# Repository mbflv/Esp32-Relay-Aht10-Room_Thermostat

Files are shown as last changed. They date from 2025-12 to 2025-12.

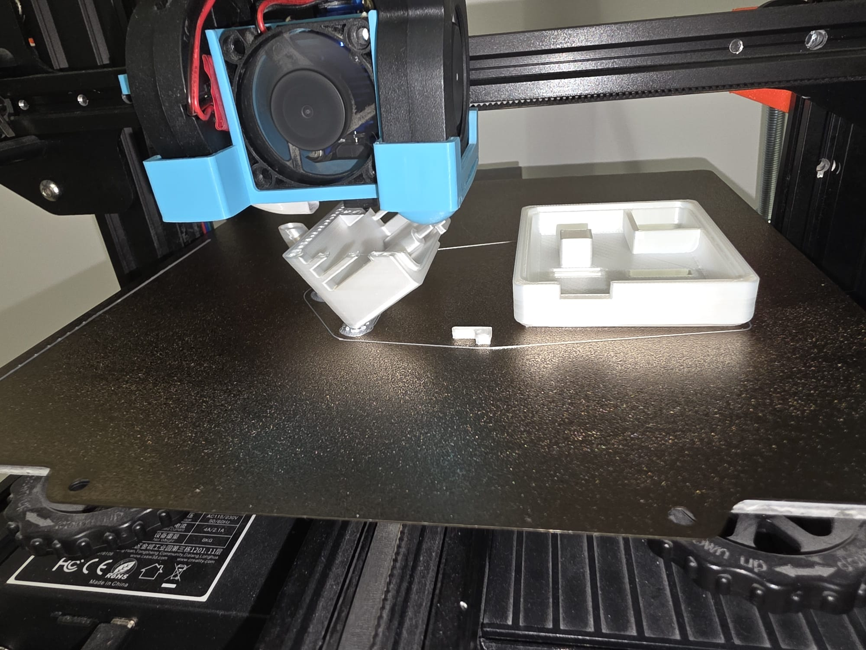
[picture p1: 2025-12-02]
Pictures/printing.png

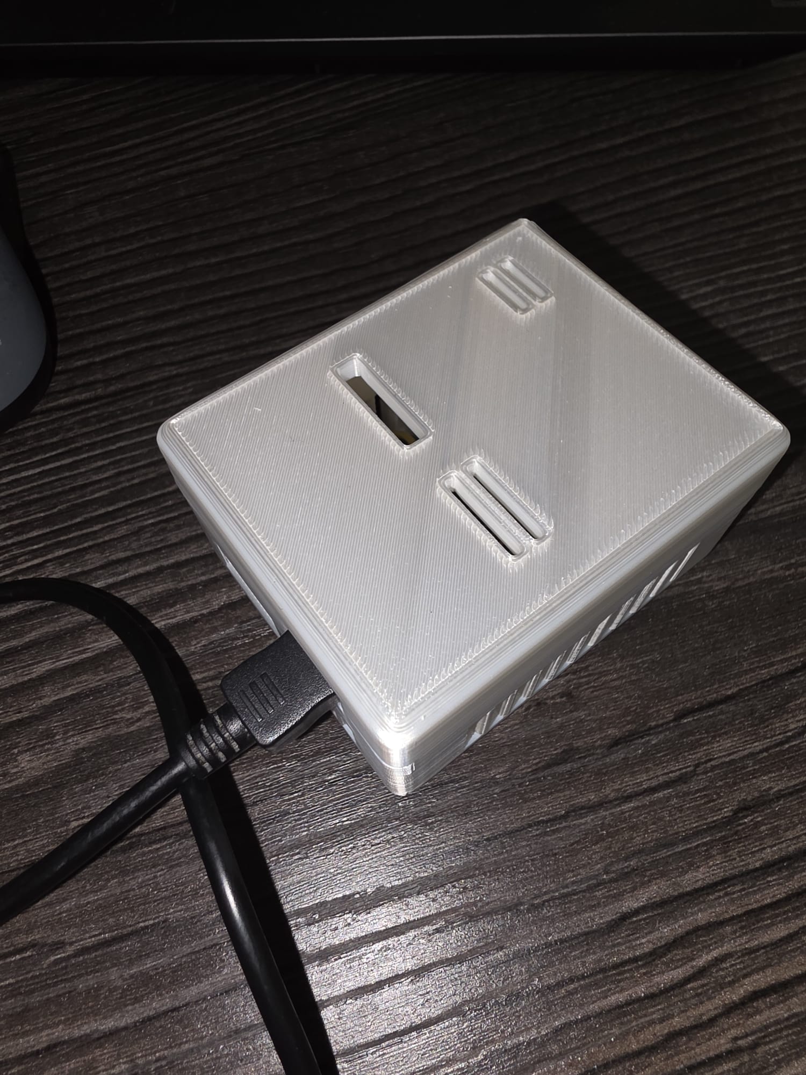
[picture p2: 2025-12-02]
Pictures/aht10_1.jpeg

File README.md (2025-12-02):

#Esp32-Relay-Aht10-Room_Thermostat

#
This is a room thermostat from at least 2 esp32 pcb.Big advantage of this system is that it use wifi local connection and AP to setup it using WEB UI.
It have many options to calibrate temperature and humidity, set up four schedule program and a graph history.
Another advantage of it is that it can support maximum 8 sensor from local Wifi.In Web UI you'll find that option to add/remove a new sensor and the check box that can make which sensor can be the main sensor who will be in control of the relay.
Esp32+relay is the brain of this configuration,it listening on port 80.you cand open a port from your rooter and acces if from outside of your house.
The big thing: NO need screw, or iron soldering, you will need only a few drops of superglue.It is not necessary to unsolder the pins from PCBs.You will can use them for the future projects.
Poll interval sensor is 60 seconds, it is permanent parameter.
Debounce is 60 seconds by default, and it can be modify.
You can install a button to factory reset using Pin 5, or you can find Factory reset button on web UI.
Another thing is about you can set offset to make correction directly on esp32+aht1 sensor UI or on relay board UI via wifi.

#
1st: esp32+relay which command your heater
  Pin connection from relay to esp board :
 IN -> pin 25
 GND -> GND
 VCC -> VN +5V

2nr esp32 + aht10 temp/hum sensor
  Pin connection from aht10 to esp board :
VIN ->3V3 +3V
GND -> GND
SCL -> G22
SDA -> G21

#
Easy method to flash esp32(Flash download Tool):
load xxxx.bootloader.bin Address: 0x1000
load xxxx.partition.bin  Address: 0x8000
load xxxx.ino.bin        Address: 0x10000
#
After flashing need to reset the board!!! after that AP will appear and you can change connection to your local wifi network!

Or you can use other IDE (Arduino IDE, etc..) and use the code to upload it.
It is nice because all code is formed in one file, and it is easy for everyone to flash it.

#
You can find in this place the *.3mf project for the case to print it for both: pcb+relay & pcb+aht10 sensor.

Material:Pla
Can be print with infill 20%
any printer any speed
recomanded bottom part to be inclined at 60degrees using manual supports and activate autobrim!

TO DO:
manual increase/decrease sensor polling time;
OTA firmare update.

I do not take responsibility for any malfunction, you do it on your own. Pay attention to the process of connecting to your heater because this relay only has an ON/OFF function. Do not connect voltage to the relay.

Goodluck!

If this project is usefull, i'd like to drink a coffe together: ( paypal: flav.op.nick@gmail.com )

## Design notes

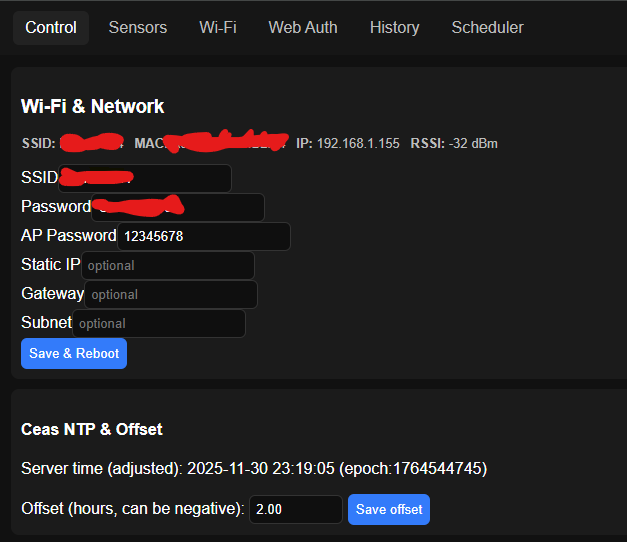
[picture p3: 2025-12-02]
Pictures/wifi.png

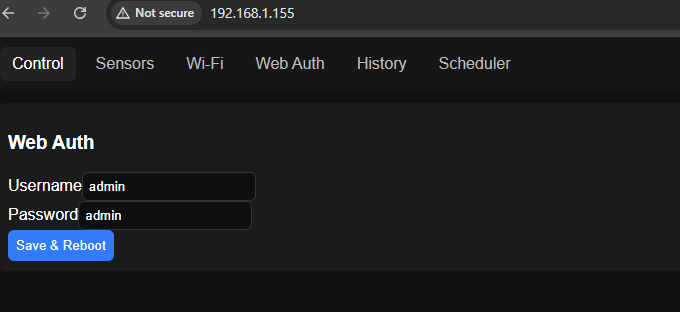
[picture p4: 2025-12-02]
Pictures/webauth.png

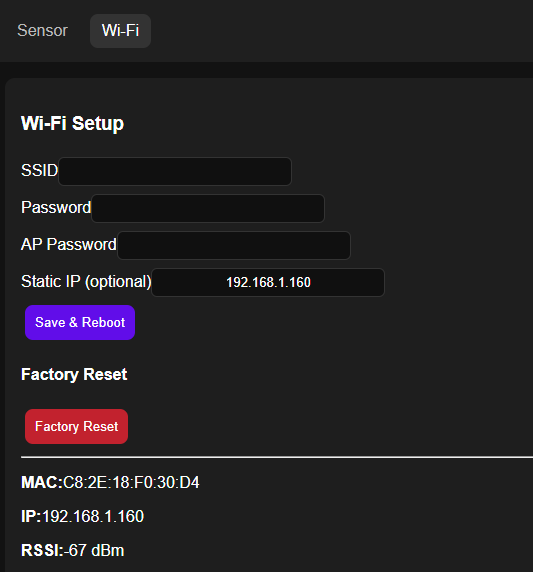
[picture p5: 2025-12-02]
Pictures/sensor-wifi.png

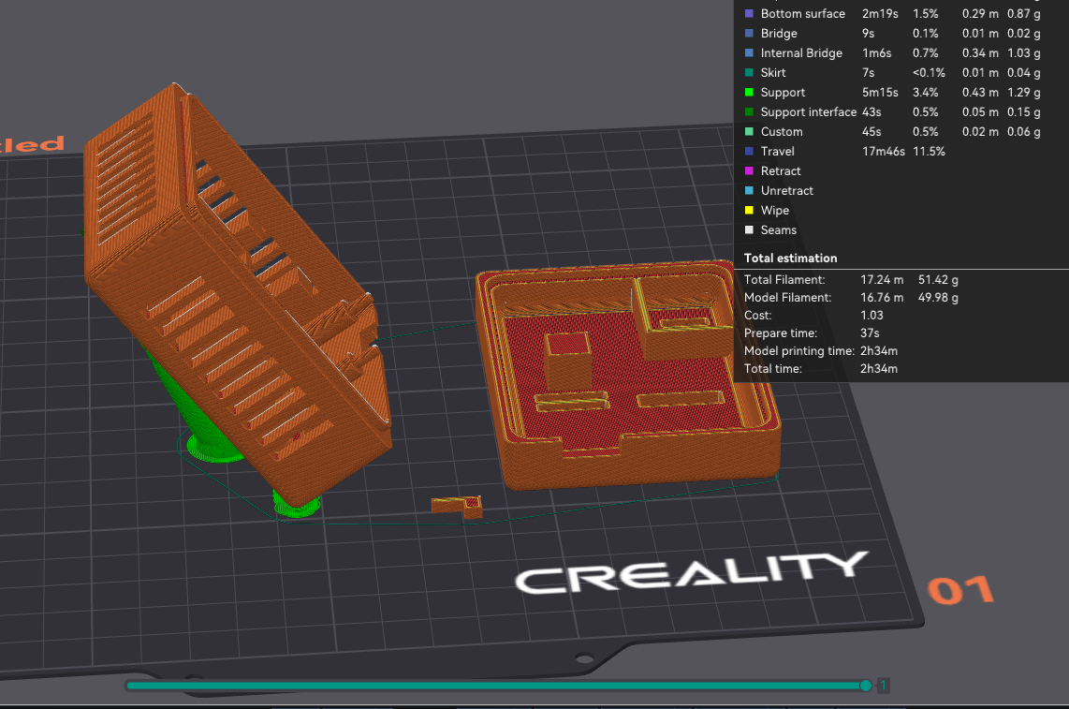
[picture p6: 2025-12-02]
Pictures/plate arrangement.png

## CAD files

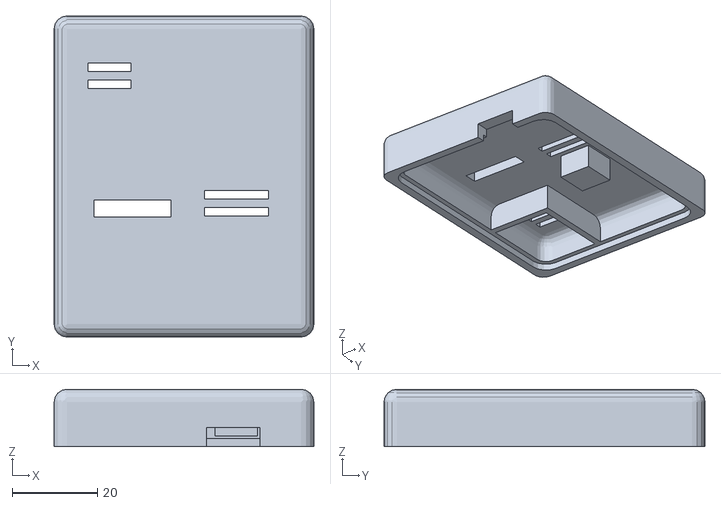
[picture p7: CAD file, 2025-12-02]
Printable Case/top.stl
61.0 x 75.4 x 13.5

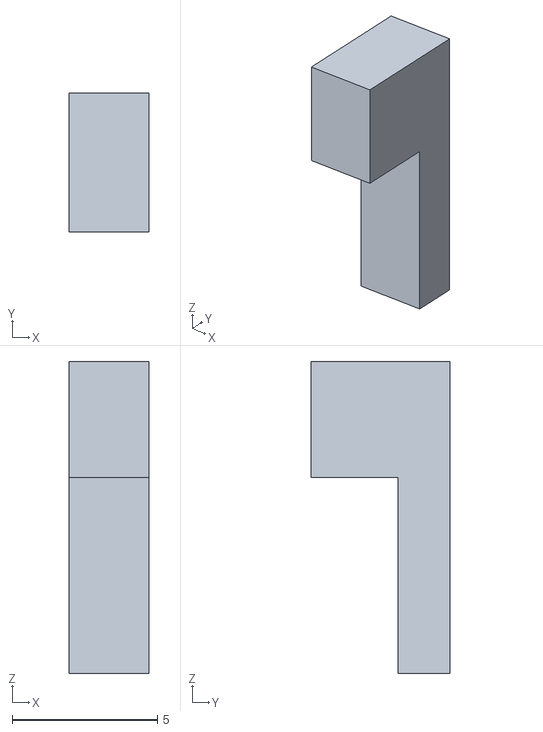
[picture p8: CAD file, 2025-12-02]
Printable Case/pin.stl
2.75 x 4.80 x 10.7

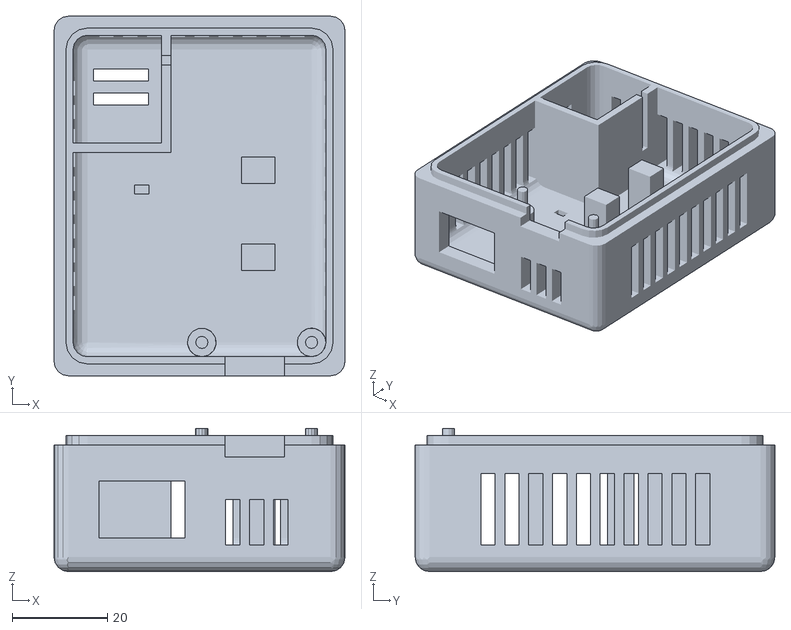
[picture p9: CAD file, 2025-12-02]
Printable Case/bot.stl
61.0 x 75.4 x 30.0

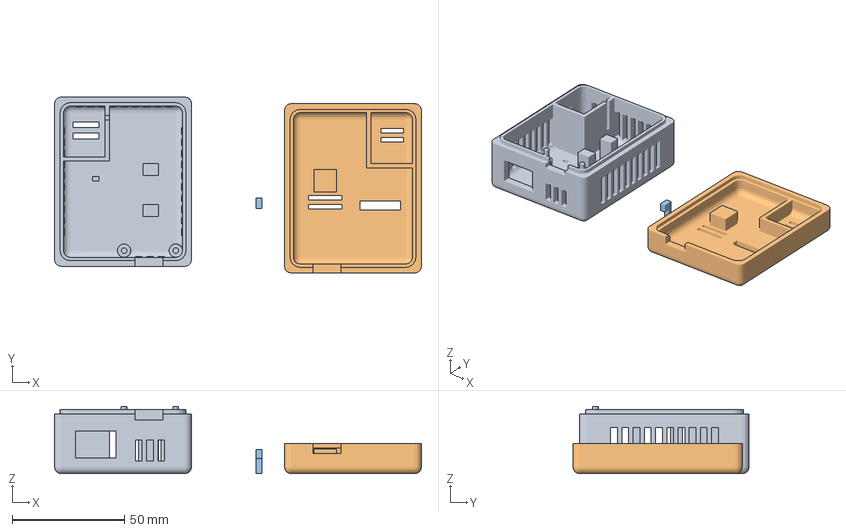
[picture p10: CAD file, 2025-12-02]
Printable Case/esp32_case_relay_aht10.3mf
163.4 x 78.3 x 30.0 mm
bot.stl
top.stl
pin.stl

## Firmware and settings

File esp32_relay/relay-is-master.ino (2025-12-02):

/* relay-with-sensors-variantA_ram_ntp_tooltip_final.ino
   For: ESP32 Dev Module
   - RAM history only
   - NTP clock with manual timezone offset (saved in Preferences)
   - History chart with hover tooltip (date/time, set.temp and temp)
   - Relay status shown on Sensors page
   - WiFi (AP + optional STA), Preferences for settings
   - Sensors polled via HTTP /json (temp/hum)
   - Scheduler + debounce + hysteresis
   - All settings persisted in Preferences
*/

#include <WiFi.h>
#include <WebServer.h>
#include <Preferences.h>
#include <HTTPClient.h>
#include <ArduinoJson.h>
#include <time.h>

#define RELAY_PIN 25
#define BUTTON_PIN 5
#define MAX_SENSORS 8
#define HISTORY_SLOTS 96            // number of samples per sensor in RAM
#define HISTORY_INTERVAL_MIN 30      // minutes between stored history samples (1 = every minute)
#define POLL_INTERVAL_MS 60000UL
#define DEFAULT_DEBOUNCE_SECS 1

WebServer server(80);
Preferences prefs;

// Auth default
String AUTH_USER = "admin";
String AUTH_PASS = "admin";

// WiFi defaults
String defaultAPPass = "12345678";
String apPass;
String savedSSID = "";
String savedPASS = "";
String staticIP = "";
String gatewayIP = "";
String subnetMask = "";

// Timezone offset in minutes (can be negative). Saved in prefs key "tz_min"
long tzOffsetMinutes = 0;

// Relay and button
bool relayState = false;
unsigned long pressStartTime = 0;
bool buttonPressed = false;

// Debounce
unsigned long lastDesiredRelayChange = 0;
unsigned long debounceSeconds = DEFAULT_DEBOUNCE_SECS * 1000UL;
bool desiredRelayState = false;

// Scheduler: 4 programs
struct Program {
  int startHour;
  int stopHour;
  float setTemp;
  bool enabled;
};
Program programs[4];

// Sensor struct
struct Sensor {
  String name;
  String ip;
  float tempOffset;
  float humOffset;
  float setTemp;
  float hysteresis;
  float lastTemp;
  float lastHum;
  bool isMain;
  bool enabled;
};
Sensor sensors[MAX_SENSORS];

// History entry (RAM)
struct HistEntry {
  uint32_t ts;
  float temp;
  float hum;
  float setTemp;
};
// In-RAM circular buffers
HistEntry histBuf[MAX_SENSORS][HISTORY_SLOTS];
uint16_t histIdx[MAX_SENSORS]; // next write position (0..HISTORY_SLOTS-1)

// Helpers
String f1(float v){ return String(v,1); }
void relayOn(){ pinMode(RELAY_PIN, OUTPUT); digitalWrite(RELAY_PIN, LOW); relayState=true; }
void relayOff(){ pinMode(RELAY_PIN, INPUT); digitalWrite(RELAY_PIN, LOW); relayState=false; } // open-drain style

// Preferences key helpers
String prefKeySensor(int idx, const char* k){
  char buf[32]; snprintf(buf, sizeof(buf), "s%d_%s", idx, k); return String(buf);
}
String prefKeyProg(int p, const char* k){ char buf[32]; snprintf(buf,sizeof(buf),"prog%d_%s",p,k); return String(buf); }

// Factory reset
void factoryReset(){
  prefs.begin("wifi", false); prefs.clear(); prefs.end();
  prefs.begin("sensors", false); prefs.clear(); prefs.end();
  prefs.begin("prog", false); prefs.clear(); prefs.end();
  delay(500);
  ESP.restart();
}

// Load / Save sensors & programs & prefs
void loadSensors(){
  prefs.begin("sensors", true);
  for(int i=0;i<MAX_SENSORS;i++){
    sensors[i].ip = prefs.getString(prefKeySensor(i,"ip").c_str(), "");
    sensors[i].name = prefs.getString(prefKeySensor(i,"name").c_str(), String("Sensor " + String(i+1)));
    sensors[i].tempOffset = prefs.getFloat(prefKeySensor(i,"toff").c_str(), 0.0f);
    sensors[i].humOffset = prefs.getFloat(prefKeySensor(i,"hoff").c_str(), 0.0f);
    sensors[i].setTemp = prefs.getFloat(prefKeySensor(i,"set").c_str(), 25.0f);
    sensors[i].hysteresis = prefs.getFloat(prefKeySensor(i,"hys").c_str(), 1.0f);
    sensors[i].isMain = prefs.getBool(prefKeySensor(i,"main").c_str(), false);
    sensors[i].lastTemp = NAN;
    sensors[i].lastHum = NAN;
    sensors[i].enabled = (sensors[i].ip.length() > 0);
  }
  prefs.end();
}

void saveSensors(){
  prefs.begin("sensors", false);
  for(int i=0;i<MAX_SENSORS;i++){
    prefs.putString(prefKeySensor(i,"ip").c_str(), sensors[i].ip);
    prefs.putString(prefKeySensor(i,"name").c_str(), sensors[i].name);
    prefs.putFloat(prefKeySensor(i,"toff").c_str(), sensors[i].tempOffset);
    prefs.putFloat(prefKeySensor(i,"hoff").c_str(), sensors[i].humOffset);
    prefs.putFloat(prefKeySensor(i,"set").c_str(), sensors[i].setTemp);
    prefs.putFloat(prefKeySensor(i,"hys").c_str(), sensors[i].hysteresis);
    prefs.putBool(prefKeySensor(i,"main").c_str(), sensors[i].isMain);
  }
  prefs.end();
}

void loadPrograms(){
  prefs.begin("prog", true);
  for(int p=0;p<4;p++){
    programs[p].startHour = prefs.getInt(prefKeyProg(p,"start").c_str(), 0);
    programs[p].stopHour  = prefs.getInt(prefKeyProg(p,"stop").c_str(), 0);
    programs[p].setTemp   = prefs.getFloat(prefKeyProg(p,"temp").c_str(), 20.0);
    programs[p].enabled   = prefs.getBool(prefKeyProg(p,"en").c_str(), false);
  }
  prefs.end();
}

void savePrograms(){
  prefs.begin("prog", false);
  for(int p=0;p<4;p++){
    prefs.putInt(prefKeyProg(p,"start").c_str(), programs[p].startHour);
    prefs.putInt(prefKeyProg(p,"stop").c_str(), programs[p].stopHour);
    prefs.putFloat(prefKeyProg(p,"temp").c_str(), programs[p].setTemp);
    prefs.putBool(prefKeyProg(p,"en").c_str(), programs[p].enabled);
  }
  prefs.end();
}

void loadWifiAuth(){
  prefs.begin("wifi", true);
  savedSSID = prefs.getString("ssid", "");
  savedPASS = prefs.getString("pass", "");
  apPass = prefs.getString("appass", defaultAPPass);
  staticIP = prefs.getString("ip", "");
  gatewayIP = prefs.getString("gw", "");
  subnetMask = prefs.getString("subnet", "");
  AUTH_USER = prefs.getString("auth_user", "admin");
  AUTH_PASS = prefs.getString("auth_pass", "admin");
  uint32_t db = prefs.getUInt("deb_ms", DEFAULT_DEBOUNCE_SECS * 1000UL);
  debounceSeconds = db;
  tzOffsetMinutes = prefs.getLong("tz_min", 0); // load timezone offset minutes
  prefs.end();
}
void saveWifiAuth(){
  prefs.begin("wifi", false);
  prefs.putString("ssid", savedSSID);
  prefs.putString("pass", savedPASS);
  prefs.putString("appass", apPass);
  prefs.putString("ip", staticIP);
  prefs.putString("gw", gatewayIP);
  prefs.putString("subnet", subnetMask);
  prefs.putString("auth_user", AUTH_USER);
  prefs.putString("auth_pass", AUTH_PASS);
  prefs.putUInt("deb_ms", (uint32_t)debounceSeconds);
  prefs.putLong("tz_min", tzOffsetMinutes);
  prefs.end();
}

// ===== In-RAM history helpers =====
void initHistoryRam(){
  for(int i=0;i<MAX_SENSORS;i++){
    histIdx[i] = 0;
    for(int s=0;s<HISTORY_SLOTS;s++){
      histBuf[i][s].ts = 0;
      histBuf[i][s].temp = NAN;
      histBuf[i][s].hum = NAN;
      histBuf[i][s].setTemp = 0;
    }
  }
}

void appendHistoryRam(int si, uint32_t ts, float temp, float hum, float setT){
  if(si<0 || si>=MAX_SENSORS) return;
  uint16_t idx = histIdx[si] % HISTORY_SLOTS;
  histBuf[si][idx].ts = ts;
  histBuf[si][idx].temp = temp;
  histBuf[si][idx].hum = hum;
  histBuf[si][idx].setTemp = setT;
  histIdx[si] = (idx + 1) % HISTORY_SLOTS;
}

// Build JSON history oldest->newest into provided JsonArray
void jsonHistoryForSensor(int si, JsonArray &arr){
  if(si<0 || si>=MAX_SENSORS) return;
  uint16_t w = histIdx[si] % HISTORY_SLOTS; // next write pos; oldest at w
  for(int i=0;i<HISTORY_SLOTS;i++){
    int pos = (w + i) % HISTORY_SLOTS;
    if(histBuf[si][pos].ts == 0) continue;
    JsonObject o = arr.createNestedObject();
    o["ts"] = histBuf[si][pos].ts - tzOffsetMinutes*60;

    //o["ts"] = histBuf[si][pos].ts;
    if(isnan(histBuf[si][pos].temp)) o["temp"] = nullptr; else o["temp"] = histBuf[si][pos].temp;
    if(isnan(histBuf[si][pos].hum))  o["hum"]  = nullptr; else o["hum"]  = histBuf[si][pos].hum;
    o["set"] = histBuf[si][pos].setTemp;
  }
}

// ===== Poll single sensor by IP (expects JSON with fields "temp" and "hum") =====
bool pollSensor(int idx){
  if(idx<0 || idx>=MAX_SENSORS) return false;
  if(!sensors[idx].enabled || sensors[idx].ip.length()==0) return false;

  HTTPClient http;
  String url = "http://" + sensors[idx].ip + "/json";
  http.setTimeout(3000);
  if(!http.begin(url)) {
    http.end();
    return false;
  }
  int code = http.GET();
  if(code==200){
    String payload = http.getString();
    http.end();
    StaticJsonDocument<256> doc;
    DeserializationError err = deserializeJson(doc, payload);
    if(!err){
      float t = NAN, h = NAN;
      if(doc.containsKey("temp")) t = doc["temp"].as<float>();
      else if(doc.containsKey("temperature")) t = doc["temperature"].as<float>();
      if(doc.containsKey("hum")) h = doc["hum"].as<float>();
      else if(doc.containsKey("humidity")) h = doc["humidity"].as<float>();
      if(!isnan(t)) sensors[idx].lastTemp = t + sensors[idx].tempOffset;
      if(!isnan(h)) sensors[idx].lastHum = h + sensors[idx].humOffset;
      return true;
    }
  } else {
    http.end();
  }
  return false;
}

// ===== JSON endpoints =====
void handleSensorsJson(){
  DynamicJsonDocument doc(2048);
  doc["relay"] = relayState ? "ON" : "OFF";
  JsonArray arr = doc.createNestedArray("sensors");
  for(int i=0;i<MAX_SENSORS;i++){
    if(!sensors[i].enabled) continue;
    JsonObject s = arr.createNestedObject();
    s["index"] = i;
    s["name"] = sensors[i].name;
    s["ip"] = sensors[i].ip;
    if(isnan(sensors[i].lastTemp)) s["temp"] = nullptr; else s["temp"] = sensors[i].lastTemp;
    if(isnan(sensors[i].lastHum))  s["hum"] = nullptr;  else s["hum"] = sensors[i].lastHum;
    s["toff"] = sensors[i].tempOffset;
    s["hoff"] = sensors[i].humOffset;
    s["set"]  = sensors[i].setTemp;
    s["hys"]  = sensors[i].hysteresis;
    s["main"] = sensors[i].isMain;
  }
  String out; serializeJson(doc, out);
  server.send(200, "application/json", out);
}

// History JSON
void handleHistoryJson(){
  if(!server.authenticate(AUTH_USER.c_str(), AUTH_PASS.c_str())) return server.requestAuthentication();
  int si = server.arg("i").toInt();
  if(si<0 || si>=MAX_SENSORS){ server.send(400,"text/plain","Bad index"); return; }
  DynamicJsonDocument doc(4096 + HISTORY_SLOTS*48);
  doc["sensor"] = sensors[si].name;
  doc["index"] = si;
  JsonArray arr = doc.createNestedArray("history");
  jsonHistoryForSensor(si, arr);
  String out; serializeJson(doc, out);
  server.send(200,"application/json", out);
}

// Time endpoint (returns adjusted epoch and ISO string)
String isoFromEpoch(time_t t){
  struct tm tmnow;
  gmtime_r(&t, &tmnow);
  char buf[32];
  snprintf(buf, sizeof(buf), "%04d-%02d-%02d %02d:%02d:%02d",
           tmnow.tm_year+1900, tmnow.tm_mon+1, tmnow.tm_mday,
           tmnow.tm_hour, tmnow.tm_min, tmnow.tm_sec);
  return String(buf);
}
void handleTimeJson(){
  time_t nowt = time(NULL);
  if(nowt <= 0) {
    server.send(200,"application/json","{\"epoch\":0,\"iso\":\"N/A\"}");
    return;
  }
  long adj = nowt + tzOffsetMinutes * 60;
  String out = "{\"epoch\":" + String((uint32_t)adj) + ",\"iso\":\"" + isoFromEpoch((time_t)adj) + "\"}";
  server.send(200,"application/json", out);
}

// ===== Web UI root (inline HTML + JS) =====
void handleRoot(){
  if(!server.authenticate(AUTH_USER.c_str(), AUTH_PASS.c_str())) return server.requestAuthentication();

  String macStr = WiFi.macAddress();
  String ipStr = (WiFi.status()==WL_CONNECTED) ? WiFi.localIP().toString() : "N/A";
  long rssi = WiFi.RSSI();
  String rssiStr = (WiFi.status()==WL_CONNECTED) ? String(rssi)+" dBm" : "N/A";

  // Build sensors HTML cards, include relay status at top
  String sensorsHtml = "";
  sensorsHtml += "<div class='card'><h3>Relay status</h3><p id='relayStateMain'>--</p></div>";
  for(int i=0;i<MAX_SENSORS;i++){
    if(!sensors[i].enabled) continue;
    sensorsHtml += "<div class='card' id='sensorCard"+String(i)+"'>";
    sensorsHtml += "<h4><input class='sname' id='name"+String(i)+"' value='"+sensors[i].name+"' onblur='saveName("+String(i)+")'></h4>";
    sensorsHtml += "<p><b>IP:</b> "+sensors[i].ip+"</p>";
    sensorsHtml += "<p>Temp: <span id='temp"+String(i)+"'>"+ (isnan(sensors[i].lastTemp)?"--":f1(sensors[i].lastTemp)) +"</span>&deg;C  Hum: <span id='hum"+String(i)+"'>"+ (isnan(sensors[i].lastHum)?"--":f1(sensors[i].lastHum)) +"</span>%</p>";
    sensorsHtml += "<p>Set: <button class='small' onclick='adjSet("+String(i)+",-0.1)'>-</button> <span id='set"+String(i)+"'>"+f1(sensors[i].setTemp)+"</span> <button class='small' onclick='adjSet("+String(i)+",0.1)'>+</button></p>";
    sensorsHtml += "<p>Hyst: <button class='small' onclick='adjHys("+String(i)+",-0.1)'>-</button> <span id='hys"+String(i)+"'>"+f1(sensors[i].hysteresis)+"</span> <button class='small' onclick='adjHys("+String(i)+",0.1)'>+</button></p>";
    sensorsHtml += "<p>Offset T: <button class='small' onclick='adjOff("+String(i)+",-0.1)'>-</button> <span id='offt"+String(i)+"'>"+f1(sensors[i].tempOffset)+"</span> <button class='small' onclick='adjOff("+String(i)+",0.1)'>+</button></p>";
    sensorsHtml += "<p>Offset H: <button class='small' onclick='adjOffH("+String(i)+",-0.1)'>-</button> <span id='offh"+String(i)+"'>"+f1(sensors[i].humOffset)+"</span> <button class='small' onclick='adjOffH("+String(i)+",0.1)'>+</button></p>";
    sensorsHtml += "<p><label><input type='radio' name='mainSensor' onchange='setMain("+String(i)+")' "+(sensors[i].isMain?"checked":"")+"> Main sensor</label></p>";
    sensorsHtml += "<p><button class='del' onclick='removeSensor("+String(i)+")'>Remove</button> <button class='btn' onclick='viewHistory("+String(i)+")'>History</button></p>";
    sensorsHtml += "</div>";
  }

  // Add-sensor UI
  bool canAdd = false;
  for(int i=0;i<MAX_SENSORS;i++){ if(!sensors[i].enabled){ canAdd=true; break; } }
  String addHtml = "";
  if(canAdd){
    addHtml += "<div class='card'><h4>Add Sensor</h4>";
    addHtml += "<label>IP</label><input id='add_ip' class='tiny' placeholder='192.168.1.50'><br>";
    addHtml += "<label>Name</label><input id='add_name' class='tiny' placeholder='Livingroom'><br>";
    addHtml += "<button class='btn' onclick='addSensor()'>Add sensor</button></div>";
  } else {
    addHtml += "<div class='card'><p>Max sensors reached ("+String(MAX_SENSORS)+")</p></div>";
  }

  // Programs UI
  String progHtml = "<div class='card'><h4>Scheduler (4 programs)</h4>";
  for(int p=0;p<4;p++){
    progHtml += "<div style='margin-bottom:6px'>";
    progHtml += "Program " + String(p+1) + ": <input class='tiny' id='p"+String(p)+"_start' value='"+String(programs[p].startHour)+"' type='number' min='0' max='23'> - ";
    progHtml += "<input class='tiny' id='p"+String(p)+"_stop' value='"+String(programs[p].stopHour)+"' type='number' min='0' max='23'> ";
    progHtml += "Set: <input class='tiny' id='p"+String(p)+"_temp' value='"+f1(programs[p].setTemp)+"' step='0.1' type='number'> ";
    progHtml += "<label><input type='checkbox' id='p"+String(p)+"_en' "+(programs[p].enabled?"checked":"")+"> Enabled</label>";
    progHtml += "</div>";
  }
  progHtml += "<button class='btn' onclick='savePrograms()'>Save Programs</button></div>";

  // Debounce UI
  String debounceHtml = "<div class='card'><h4>Debounce</h4>";
  debounceHtml += "Debounce (seconds): <input class='tiny' id='deb' value='"+String(debounceSeconds/1000)+"' type='number' min='0'> <button class='btn' onclick='saveDebounce()'>Save</button></div>";

  // Timezone UI
  String tzHtml = "<div class='card'><h4>Ceas NTP & Offset</h4>";
  tzHtml += "<p>Server time (adjusted): <span id='srv_time'>...</span></p>";
  tzHtml += "Offset (hours, can be negative): <input class='tiny' id='tz_hours' value='"+String((float)tzOffsetMinutes/60.0,2)+"' step='0.25' type='number'> ";
  tzHtml += "<button class='btn' onclick='saveTZ()'>Save offset</button></div>";

  // Compose page using String(...) wrappers to avoid operator ambiguity
  String page = String(R"rawliteral(
<!doctype html><html><head><meta name='viewport' content='width=device-width,initial-scale=1'>
<title>Relay + Sensors (Variant A - RAM history)</title>
<style>
:root{--bg:#111;--card:#1b1b1b;--accent:#2979ff;--muted:#bdbdbd;--white:#fff}
body{background:var(--bg);color:var(--white);margin:0;font-family:Arial,Helvetica,sans-serif}
.header{padding:10px 14px;background:#161616;display:flex;gap:8px;flex-wrap:wrap}
.tab{padding:8px 12px;color:var(--muted);cursor:pointer}
.tab.active{color:var(--white);background:#222;border-radius:6px}
.container{padding:12px}
.card{background:var(--card);padding:10px;border-radius:8px;margin-bottom:10px}
.btn{background:var(--accent);padding:8px;border:none;color:#fff;border-radius:6px;cursor:pointer}
.small{width:26px;height:26px;border-radius:6px;border:none;background:#333;color:#fff;cursor:pointer}
.del{background:#c62828;padding:6px;border:none;color:#fff;border-radius:6px;cursor:pointer}
.input{width:160px;padding:6px;border-radius:6px;border:1px solid #333;background:#0f0f0f;color:#fff}
.tiny{width:80px;padding:6px;border-radius:6px;border:1px solid #333;background:#0f0f0f;color:#fff}
.sname{width:180px;padding:6px;border-radius:6px;border:1px solid #333;background:#0f0f0f;color:#fff}
.sensor-grid{display:grid;grid-template-columns:repeat(auto-fit,minmax(260px,1fr));gap:8px}
.info{font-size:13px;color:var(--muted)}
.chart-wrap{width:100%;height:320px;background:#0b0b0b;border-radius:8px;padding:8px;position:relative}
#tooltip{position:absolute;pointer-events:none;background:#222;padding:6px;border-radius:6px;border:1px solid #444;display:none;font-size:12px}
</style></head><body>
<div class='header'>
  <div class='tab active' id='tabControl' onclick="showTab('control')">Control</div>
  <div class='tab' id='tabSensors' onclick="showTab('sensors')">Sensors</div>
  <div class='tab' id='tabWifi' onclick="showTab('wifi')">Wi-Fi</div>
  <div class='tab' id='tabAuth' onclick="showTab('auth')">Web Auth</div>
  <div class='tab' id='tabHistory' onclick="showTab('history')">History</div>
  <div class='tab' id='tabSched' onclick="showTab('sched')">Scheduler</div>
</div>
<div class='container'>

<div id='controlTab'>
  <div class='card'>
    <h3>Control</h3>
    <p class='info'>Advanced relay control is available via Sensors page and automatic rules (scheduler/hysteresis).</p>

    <canvas id='tempGauge' width='300' height='150'></canvas>

    <div style='margin-top:10px;'>
      <button class='small' onclick='adjustSet(-0.1)'>-</button>
      <span id='setTempVal'>--</span> &deg;C
      <button class='small' onclick='adjustSet(0.1)'>+</button>
    </div>

    <p>Current Temp: <span id='currentTempVal'>--</span> &deg;C</p>
    <p>Humidity: <span id='currentHumVal'>--</span> %</p>
    <p>Status: <span id='heatingStatus'>--</span></p>
    <p class='info'>----------------------------------</p>
    <p class='info'>Developed by Flaviu.Inspired by your needs.</p>
  </div>
</div>

<div id='sensorsTab' style='display:none'>
  <div class='card'>
    <h3>Sensors</h3>
    <div class='sensor-grid'>
)rawliteral") + sensorsHtml + String(R"rawliteral(
    </div>
  </div>
  )rawliteral") + addHtml + String(R"rawliteral(
</div>

<div id='wifiTab' style='display:none'>
  <div class='card'>
    <h3>Wi-Fi & Network</h3>
    <p class='info'><b>SSID:</b> )rawliteral") + savedSSID + String(R"rawliteral( &nbsp; <b>MAC:</b> )rawliteral") + macStr + String(R"rawliteral( &nbsp; <b>IP:</b> )rawliteral") + ipStr + String(R"rawliteral( &nbsp; <b>RSSI:</b> )rawliteral") + rssiStr + String(R"rawliteral(</p>
    <form onsubmit="saveWifi();return false;">
      <label>SSID</label><input id='ssid' class='input' value=')rawliteral") + savedSSID + String(R"rawliteral('><br>
      <label>Password</label><input id='pass' class='input' value=')rawliteral") + savedPASS + String(R"rawliteral('><br>
      <label>AP Password</label><input id='appass' class='input' value=')rawliteral") + apPass + String(R"rawliteral('><br>
      <label>Static IP</label><input id='sip' class='input' value=')rawliteral") + staticIP + String(R"rawliteral(' placeholder='optional'><br>
      <label>Gateway</label><input id='gw' class='input' value=')rawliteral") + gatewayIP + String(R"rawliteral(' placeholder='optional'><br>
      <label>Subnet</label><input id='sm' class='input' value=')rawliteral") + subnetMask + String(R"rawliteral(' placeholder='optional'><br>
      <button class='btn' type='submit'>Save & Reboot</button>
    </form>
  </div>
  )rawliteral") + tzHtml + String(R"rawliteral(
</div>
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
void loop(){
  server.handleClient();

  // Button handling: short toggle, long reset
  bool pressed = (digitalRead(BUTTON_PIN) == LOW);
  if(pressed && !buttonPressed){ buttonPressed=true; pressStartTime = millis(); }
  else if(!pressed && buttonPressed){
    unsigned long duration = millis() - pressStartTime;
    buttonPressed=false;
    if(duration < 2000){
      desiredRelayState = !relayState;
      lastDesiredRelayChange = millis();
    } else if(duration >= 10000){
      factoryReset();
    }
  }

  unsigned long now = millis();
  // Poll sensors periodically
  if(now - lastPoll >= POLL_INTERVAL_MS){
    lastPoll = now;
    uint32_t ts = time(NULL) + tzOffsetMinutes*60;
    for(int i=0;i<MAX_SENSORS;i++){
      if(sensors[i].enabled){
        if(pollSensor(i)){
          appendHistoryRam(i, ts, sensors[i].lastTemp, sensors[i].lastHum, sensors[i].setTemp);
        }
      }
    }
    applySchedulesIfAny();
  }

  // Relay control by main sensor hysteresis (if main exists)
  int mainIdx = -1;
  for(int i=0;i<MAX_SENSORS;i++) if(sensors[i].enabled && sensors[i].isMain){ mainIdx = i; break; }
  if(mainIdx >= 0 && !isnan(sensors[mainIdx].lastTemp)){
    float t = sensors[mainIdx].lastTemp;
    float setv = sensors[mainIdx].setTemp;
    float hys = sensors[mainIdx].hysteresis;
    if(t >= setv + hys) { desiredRelayState = false; lastDesiredRelayChange = lastDesiredRelayChange==0 ? millis() : lastDesiredRelayChange; }
    else if(t <= setv - hys) { desiredRelayState = true; lastDesiredRelayChange = lastDesiredRelayChange==0 ? millis() : lastDesiredRelayChange; }
  }

  evaluateDesiredRelay();
  maybeStoreHistory();

  delay(10);
}

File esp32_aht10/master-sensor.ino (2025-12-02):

#include <WiFi.h>
#include <WebServer.h>
#include <Preferences.h>
#include <Wire.h>
#include <Adafruit_AHTX0.h>

WebServer server(80);
Preferences prefs;
Adafruit_AHTX0 aht;

#define BUTTON_PIN 5

float tempOffset = 0.0;
float humOffset = 0.0;
float curTemp = 0.0;
float curHum = 0.0;

String defaultAPPass = "12345678";
String apPass;
String savedSSID = "";
String savedPASS = "";
String staticIP = "";

unsigned long pressStartTime = 0;
bool buttonPressed = false;

// ======== Helpers ========
String f1(float v){ return String(v,1); }

// ======== Button ========
void handleButton(){
  bool pressed = (digitalRead(BUTTON_PIN)==LOW);
  if(pressed && !buttonPressed){ buttonPressed=true; pressStartTime=millis();}
  else if(!pressed && buttonPressed){
    unsigned long duration = millis()-pressStartTime;
    buttonPressed=false;
    if(duration >= 10000){ // long press -> factory reset
      prefs.begin("sensor",false); prefs.clear(); prefs.end();
      prefs.begin("wifi",false); prefs.clear(); prefs.end();
      delay(500);
      ESP.restart();
    }
  }
}

// ======== Preferences ========
void loadPrefs(){
  prefs.begin("sensor",false);
  tempOffset = prefs.getFloat("toff",0.0);
  humOffset  = prefs.getFloat("hoff",0.0);
  prefs.end();

  prefs.begin("wifi",false);
  savedSSID = prefs.getString("ssid","");
  savedPASS = prefs.getString("pass","");
  apPass = prefs.getString("appass",defaultAPPass);
  staticIP = prefs.getString("ip","");
  prefs.end();
}

void savePrefs(){
  prefs.begin("sensor",false);
  prefs.putFloat("toff",tempOffset);
  prefs.putFloat("hoff",humOffset);
  prefs.end();
}

void saveWifi(String ssid,String pass,String ap,String ip){
  prefs.begin("wifi",false);
  prefs.putString("ssid",ssid);
  prefs.putString("pass",pass);
  prefs.putString("appass",ap);
  prefs.putString("ip",ip);
  prefs.end();
}

// ======== JSON ========
void handleJSON(){
  String js="{\"temp\":"+f1(curTemp)+",\"hum\":"+f1(curHum)+",\"toff\":"+f1(tempOffset)+",\"hoff\":"+f1(humOffset)+
            ",\"mac\":\""+WiFi.macAddress()+"\",\"ip\":\""+((WiFi.status()==WL_CONNECTED)?WiFi.localIP().toString():"N/A")+
            "\",\"rssi\":"+String(WiFi.RSSI())+"}";
  server.send(200,"application/json",js);
}

// ======== Web UI ========
void handleRoot(){
  String macStr = WiFi.macAddress();
  String ipStr  = (WiFi.status()==WL_CONNECTED)?WiFi.localIP().toString():"N/A";
  long rssi = WiFi.RSSI();
  String rssiStr = (WiFi.status()==WL_CONNECTED)?String(rssi)+" dBm":"N/A";

  String page = R"rawliteral(
<!doctype html><html>
<head>
<meta name='viewport' content='width=device-width,initial-scale=1'>
<title>Sensor Node</title>
<style>
:root{--bg:#121212;--card:#1e1e1e;--accent:#6200EE;--muted:#bbbbbb;--white:#fff}
body{background:var(--bg);color:var(--white);margin:0;font-family:Roboto,Arial}
.header{padding:14px 16px;background:#1f1f1f;display:flex;gap:10px}
.tab{padding:8px 12px;color:var(--muted);cursor:pointer}
.tab.active{color:var(--white);background:#333;border-radius:8px}
.container{padding:16px}
.card{background:var(--card);padding:16px;border-radius:10px;margin-bottom:14px}
.btn{background:var(--accent);padding:10px;border:none;color:#fff;border-radius:8px;cursor:pointer;margin:4px}
.input{width:220px;padding:6px;margin:4px 0;border-radius:6px;border:1px solid #333;background:#101010;color:#fff;text-align:center}
.offset-btn{width:32px;height:32px;background:#6200EE;color:#fff;border:none;border-radius:8px;font-size:18px;margin:2px;cursor:pointer}
</style>
</head>
<body>
<div class='header'>
  <div class='tab active' id='tabSensor' onclick="showTab('sensor')">Sensor</div>
  <div class='tab' id='tabWifi' onclick="showTab('wifi')">Wi-Fi</div>
</div>
<div class='container'>

<div id='sensorTab'>
  <div class='card'>
    <h3>Sensor Data</h3>
    <p>Temperature: <span id='curTemp'>--</span>&deg;C 
      <button class='offset-btn' onclick="changeOffset('temp',-0.1)">-</button>
      <button class='offset-btn' onclick="changeOffset('temp',0.1)">+</button>
    </p>
    <p>Humidity: <span id='curHum'>--</span>% 
      <button class='offset-btn' onclick="changeOffset('hum',-0.1)">-</button>
      <button class='offset-btn' onclick="changeOffset('hum',0.1)">+</button>
    </p>
    <p>Temp Offset: <span id='toff'>0.0</span></p>
    <p>Hum Offset: <span id='hoff'>0.0</span></p>
  </div>
</div>

<div id='wifiTab' style='display:none'>
  <div class='card'>
    <h3>Wi-Fi Setup</h3>
    <label>SSID</label><input id='ssid' class='input'><br>
    <label>Password</label><input id='pass' class='input'><br>
    <label>AP Password</label><input id='appass' class='input'><br>
    <label>Static IP (optional)</label><input id='ip' class='input'><br>
    <button class='btn' onclick="saveWifi()">Save & Reboot</button>
    <h4>Factory Reset</h4>
    <button class='btn' style='background:#c62828' onclick="factoryReset()">Factory Reset</button>
    <hr>
    <p><b>MAC:</b>)rawliteral"+macStr+R"rawliteral(</p>
    <p><b>IP:</b>)rawliteral"+ipStr+R"rawliteral(</p>
    <p><b>RSSI:</b>)rawliteral"+rssiStr+R"rawliteral(</p>
  </div>
</div>

</div>
<script>
async function fetchJSON(path){try{let r=await fetch(path);return await r.json();}catch(e){return null;}}
async function updateUI(){
  let data=await fetchJSON('/json');
  if(data){
    // Only update sensor live data
document.getElementById('curTemp').innerText=data.temp.toFixed(1);
document.getElementById('curHum').innerText=data.hum.toFixed(1);
document.getElementById('toff').innerText=data.toff.toFixed(1);
document.getElementById('hoff').innerText=data.hoff.toFixed(1);

// Update Wi-Fi fields only once when page loads
if (!window.wifiFieldsLoaded) {
    document.getElementById('ssid').value=data.ssid || '';
    document.getElementById('pass').value=data.pass || '';
    document.getElementById('appass').value=data.ap || '';
    document.getElementById('ip').value=data.ip || '';
    window.wifiFieldsLoaded = true;
}

  }
}

// Offset buttons
function changeOffset(type,val){
  let url='/saveoffsets?'+type+'='+val;
  fetch(url).then(()=>updateUI());
}

async function saveWifi(){
  let s=document.getElementById('ssid').value;
  let p=document.getElementById('pass').value;
  let ap=document.getElementById('appass').value;
  let ip=document.getElementById('ip').value;
  await fetch('/savewifi?s='+s+'&p='+p+'&ap='+ap+'&ip='+ip);
  alert('Saved, rebooting');
}

async function factoryReset(){if(confirm('Reset to factory?')) await fetch('/reset');}

function showTab(t){
  document.getElementById('sensorTab').style.display=(t=='sensor'?'block':'none');
  document.getElementById('wifiTab').style.display=(t=='wifi'?'block':'none');
  document.getElementById('tabSensor').classList.toggle('active', t=='sensor');
  document.getElementById('tabWifi').classList.toggle('active', t=='wifi');
}

updateUI(); setInterval(updateUI,2000);
</script>
</body></html>
)rawliteral";

  server.send(200,"text/html",page);
}
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
